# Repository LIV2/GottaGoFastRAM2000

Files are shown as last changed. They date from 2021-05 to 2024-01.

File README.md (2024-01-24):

# GottaGoFastRAM2000 8MB Autoconfig Fast RAM

This is an 8MB Autoconfig Fast RAM for the Amiga 2000 

Special thanks to [GadgetUK164](https://www.youtube.com/user/GadgetUK164) and sparxUK for their help testing this.

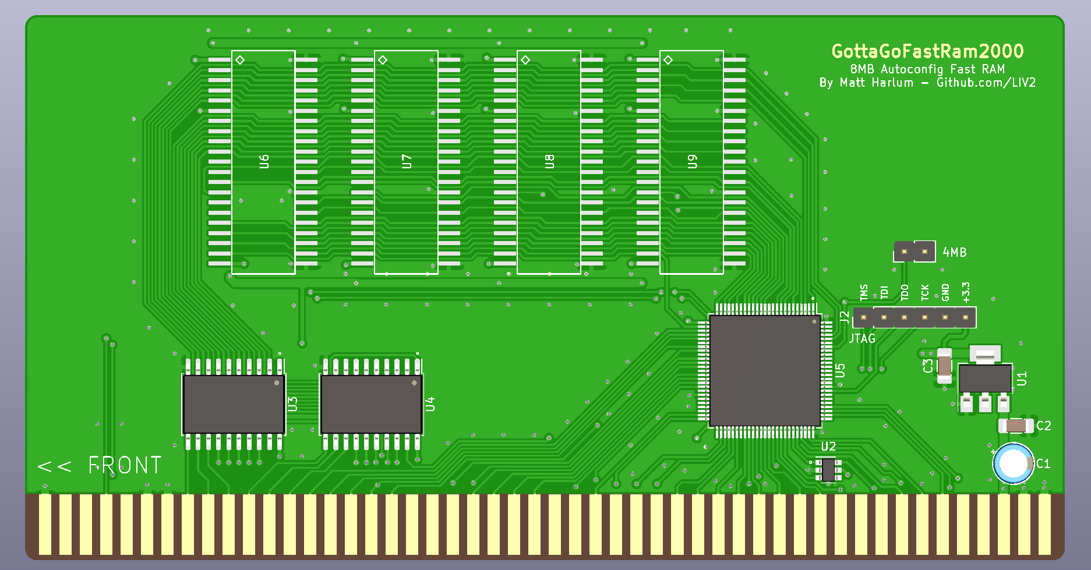
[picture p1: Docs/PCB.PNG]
PCB


## Table of contents
1. [Status](#status)
1. [Features](#features)
1. [Firmware](#firmware)
1. [PCB Ordering](#ordering-pcbs)
1. [Jumpers](#jumpers)
1. [Bill of materials](#bill-of-materials)
1. [Troubleshooting](#troubleshooting)

## Status

This is tested and working

## Features

* 8MB of Fast RAM
* Auto-sizing - The RAM board will coexist with other devices by autosizing to fit the remaining free Zorro II memory space

## Firmware

There are two different firmwares available for this card.
1. [Standard autosizing](https://github.com/LIV2/GottaGoFastRAM2000/raw/master/Binary/XC9572XL/gottagofast2000.jed) - This Firmware will autosize trying in this order: 8MB -> 4MB -> 2MB -> 1MB until it can fit in the remaining space
2. [6MB autosizing](https://github.com/LIV2/GottaGoFastRAM2000/raw/master/Binary/XC9572XL/gottagofast2000-6MB.jed) - This will try to offer 8MB then 6MB (in a block of 2MB + 4MB) to maximize space i.e when using a bridgeboard that needs 512K itself

## PCB Ordering

For best results the boards should be manufactured with the "Gold Fingers" option so that the edge connector will survive many insertion/removal cycles

## Jumpers

4MB: Forces the board to appear as a 4MB board rather than 8MB

### Bill of materials

|Component|Location|QTY|Link|Note|
|---|---|---|----|----|
|LM1117-3.3 SOT-223|U1|1|[Mouser](https://www.mouser.com/ProductDetail/926-LM1117IMP3.3NOPB)||
|XC9572XL-10TQ100C|U5|1|[Mouser](https://www.mouser.com/ProductDetail/217-C9572XL-10TQ100C)|Can be substituted with XC95144XL-10-TQ100|
|74LS245 SOIC|U3,U4|2|[Mouser](https://www.mouser.com/ProductDetail/595-SN74LS245DWR)||
|74LVC2G07|U2|1|[Mouser](https://www.mouser.com/ProductDetail/595-SN74LVC2G07DBVR)|*Optional - See below|
|5v 1MBx16 DRAM, SOJ-42  i.e  <br/>K4E151611<br/>K4F151611<br/>MT4C1M16E5<br/>GM71C18163C<br/>AS4C1M16E5 etc.|U6,U7,U8,U9|4|Aliexpress, Ebay etc||
|0.1uF Ceramic capacitor, 0805|C4-25|22|[Mouser](https://www.mouser.com/ProductDetail/581-08055C104K)||
|10uF Ceramic capacitor, 1206|C2,C3|2|[Mouser](https://www.mouser.com/ProductDetail/80-C1206C106K4R)||
|100uF Electrolytic Capacitor|C1|1|[Mouser](https://www.mouser.com/ProductDetail/667-16SEPC100M)||
|10K Resistor, 0805|R1|1|[Mouser](https://www.mouser.com/ProductDetail/754-RR1220P-103D)|

\* U2 buffers the cards generated DTACK and OVR signals - In a pinch this can be left out but you will run into problems with the A2091 and some other devices so it is best to fit this and save yourself the headache

## Troubleshooting
* **Problem**: System does not boot, the power LED does not change brightness  
  **Solution**: Possible incorrect orientation/faulty ic in U2 - check orientation and/or remove this IC and try again

* **Problem**: My bridgeboard doesn't work when this card is installed  
  **Solution**: The bridgeboard needs 512K of the 8MB expansion space for its own use, you will need to move the ram board to the leftmost slot and I recommend flashing the [6MB Firmware](https://github.com/LIV2/GottaGoFastRAM2000/raw/master/Binary/XC9572XL/gottagofast2000-6MB.jed) to maximise the amount of memory offered when used with the bridgeboard

* **Problem**: My system is unstable / graphical corruption when using this board but it passes a memory test in ATK/DiagROM etc  
  **Solution**: Check that your Amiga 2000 has the correct buffers installed in U600-605. U600,601,603,604 __must__ be 74LS245 and U602/605 should be 74ALS245 but might be 74LS245 in some A2000 revisions.  
  If you have used anything else (like 74HCT245) for these you will run into issues with this board and many others.

* **Problem**: When used with a bridgeboard/other cards I get a gray screen telling me the card has been "SHUT"  
  **Solution**: Some other board is using some of the 8MB space, so the card will be told to shutup and will reappear offering 4MB then 2, 1 etc.  
  On Kick 1.3-3.1 the system will not alert you to this happening and will continue to boot (this is used to do the autosizing) but newer versions "helpfully" tell you about this condition.  
  If using one of these newer kickstart versions with a Bridgeboard I'd recommend flashing the [6MB Firmware](https://github.com/LIV2/GottaGoFastRAM2000/raw/master/Binary/XC9572XL/gottagofast2000-6MB.jed)  
  Another option would be to write the firmware to offer multiple 2MB blocks until it is shut up which unfortunately doesn't work, because Kickstart 1.3-3.1 will throw a yellow screen if the last board in the chain was shut up, and newer versions will throw the gray screen telling us the board has been shut-up.
  
* **Problem**: With the board installed I get a red screen saying that this board is defective  
  **Solution**: This usually means that one of the RAM chips are faulty or there could be bad soldering.  
  Remove all other Zorro cards, boot up [ATK](https://github.com/keirf/amiga-stuff/releases) or Diagrom and do a manual memory test with the individual ranges listed in the memory map below.  
  Consult the memory map below to figure out which RAM chip is being reported faulty.
  If the same bits are reported as faulty across multiple of the address ranges check for bad soldering around the RAM chips and the buffers at U3&U4.  

### Memory Map
|Address range|Chip|
|---|----|
|200000-3FFFFF|U6|
|400000-5FFFFF|U7|
|600000-7FFFFF|U8|
|800000-9FFFFF|U9|

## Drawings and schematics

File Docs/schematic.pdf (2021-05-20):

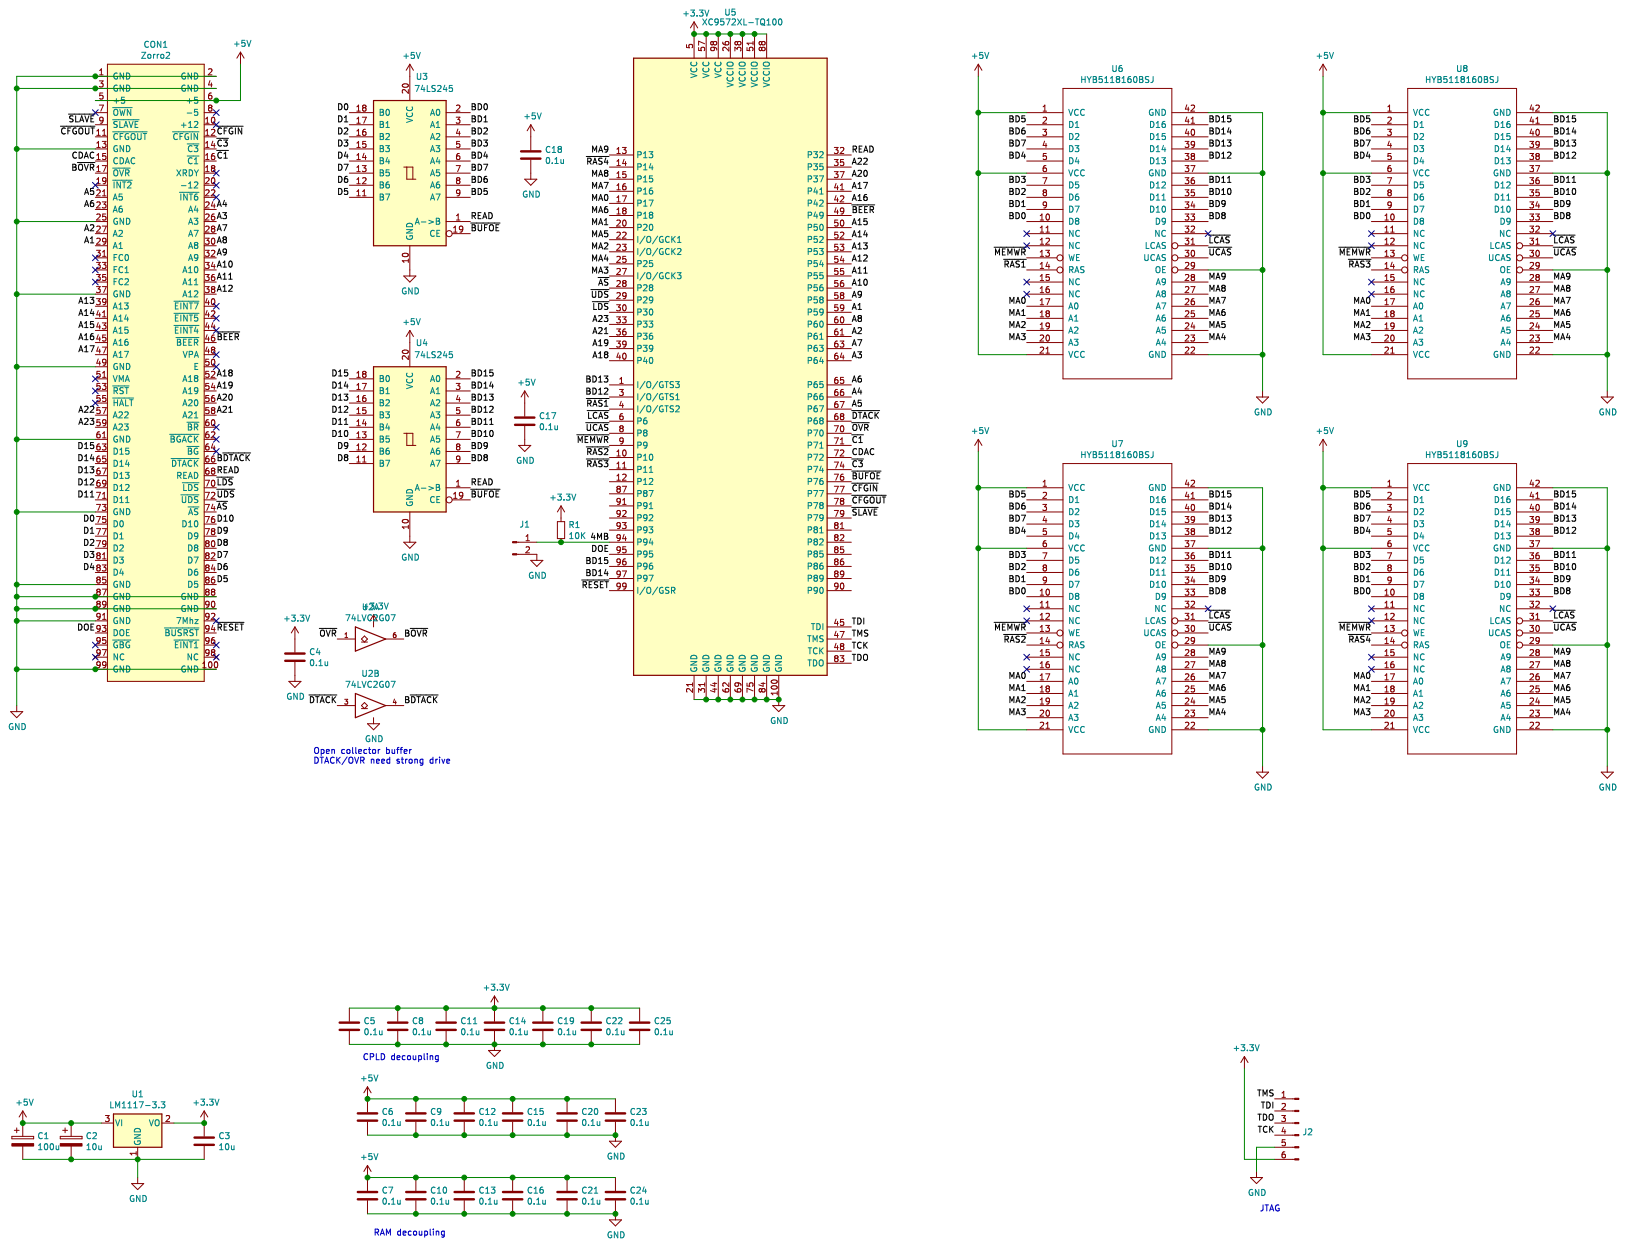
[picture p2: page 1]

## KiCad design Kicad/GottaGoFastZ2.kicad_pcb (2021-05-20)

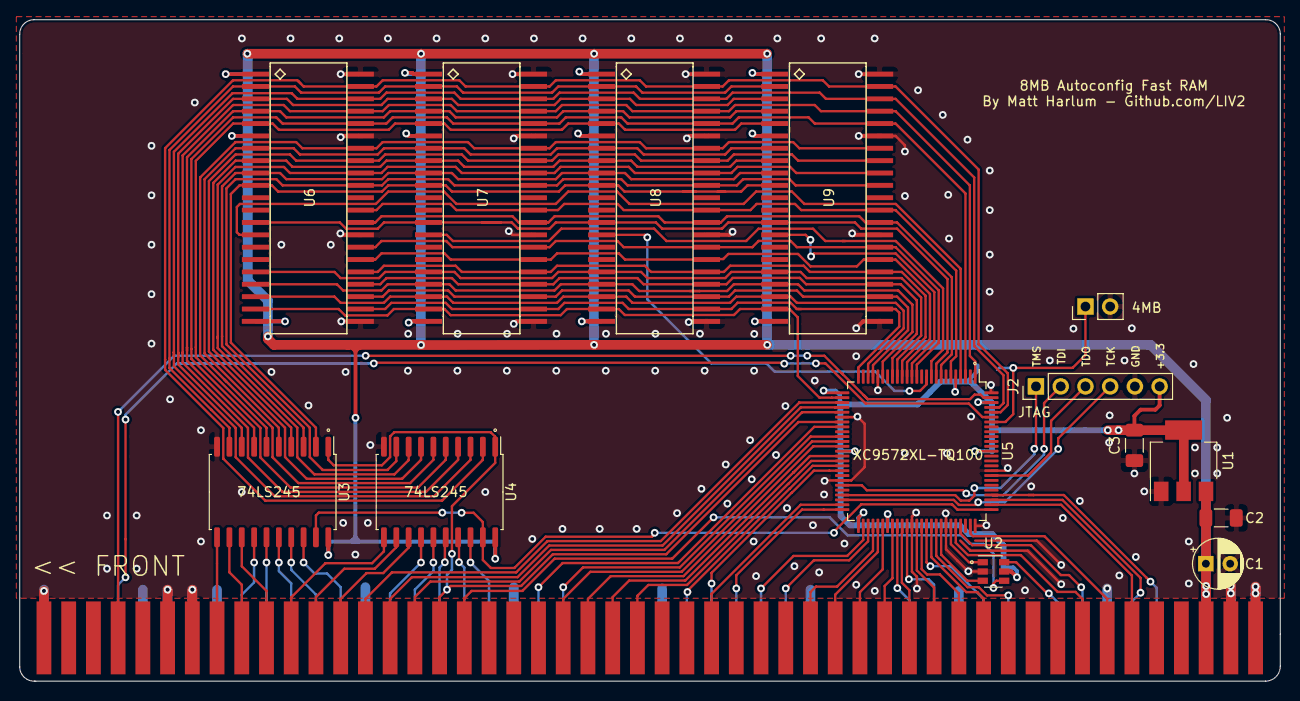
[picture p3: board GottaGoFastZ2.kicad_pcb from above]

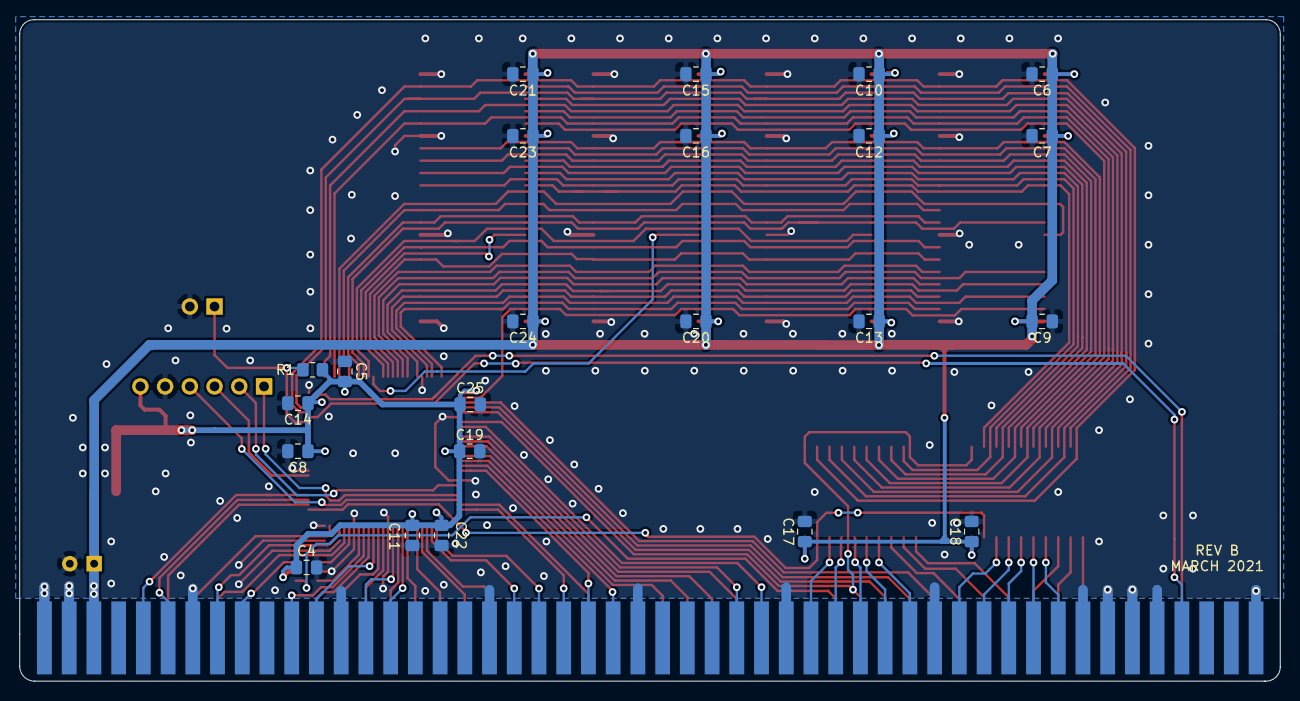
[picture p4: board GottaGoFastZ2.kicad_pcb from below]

Board: 2 copper layers, 129.5 x 67.9 mm, 38 parts (23 on the bottom side), 98 nets.

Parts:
C1: 100u; CP_Radial_D5.0mm_P2.50mm
C2, C3: 10u; C_1206_3216Metric_Pad1.33x1.80mm_HandSolder
C4, C5, C6, C7, C8, C9, C10, C11, C12, C13, C14, C15, C16, C17, C18, C19, C20, C21, C22, C23, C24, C25: 0.1u; C_0805_2012Metric_Pad1.18x1.45mm_HandSolder
CON1: Zorro2; Zorro2-CardEdge
J1: 4MB; PinHeader_1x02_P2.54mm_Vertical
J2: Conn_01x06_Male; PinHeader_1x06_P2.54mm_Vertical
R1: 10K; R_0805_2012Metric_Pad1.20x1.40mm_HandSolder
U1: LM1117-3.3; SOT-223-3_TabPin2
U2: 74LVC2G07; SOT-23-6
U3, U4: 74LS245; SOIC-20W_7.5x12.8mm_P1.27mm
U5: XC9572XL-TQ100; TQFP-100_14x14mm_P0.5mm
U6, U7, U8, U9: HYB5118160BSJ; SOJ-42-LongPads

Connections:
+3V3: C3.1, C4.1, C5.1, C8.1, C11.1, C14.1, C19.1, C22.1, C25.1, J2.6, R1.1, U1.2, U2.5, U5.5, U5.26, U5.38, U5.51, U5.57, U5.88, U5.98
+5V: C1.1, C2.1, C6.1, C7.1, C9.1, C10.1, C12.1, C13.1, C15.1, C16.1, C17.1, C18.1, C20.1, C21.1, C23.1, C24.1, CON1.5, CON1.6, U1.3, U3.20, U4.20, U6.1, U6.6, U6.21, U7.1, U7.6, U7.21, U8.1, U8.6, U8.21, U9.1, U9.6, U9.21
/4MB: J1.1, R1.2, U5.94
/A1: CON1.29, U5.59
/A2: CON1.27, U5.61
/A3: CON1.26, U5.64
/A4: CON1.24, U5.66
/A5: CON1.21, U5.67
/A6: CON1.23, U5.65
/A7: CON1.28, U5.63
/A8: CON1.30, U5.60
/A9: CON1.32, U5.58
/A10: CON1.34, U5.56
/A11: CON1.36, U5.55
/A12: CON1.38, U5.54
/A13: CON1.39, U5.53
/A14: CON1.41, U5.52
/A15: CON1.43, U5.50
/A16: CON1.45, U5.42
/A17: CON1.47, U5.41
/A18: CON1.52, U5.40
/A19: CON1.54, U5.39
/A20: CON1.56, U5.37
/A21: CON1.58, U5.36
/A22: CON1.57, U5.35
/A23: CON1.59, U5.33
/BD0: U3.2, U6.10, U7.10, U8.10, U9.10
/BD1: U3.3, U6.9, U7.9, U8.9, U9.9
/BD2: U3.4, U6.8, U7.8, U8.8, U9.8
/BD3: U3.5, U6.7, U7.7, U8.7, U9.7
/BD4: U3.6, U6.5, U7.5, U8.5, U9.5
/BD5: U3.9, U6.2, U7.2, U8.2, U9.2
/BD6: U3.8, U6.3, U7.3, U8.3, U9.3
/BD7: U3.7, U6.4, U7.4, U8.4, U9.4
/BD8: U4.9, U6.33, U7.33, U8.33, U9.33
/BD9: U4.8, U6.34, U7.34, U8.34, U9.34
/BD10: U4.7, U6.35, U7.35, U8.35, U9.35
/BD11: U4.6, U6.36, U7.36, U8.36, U9.36
/BD12: U4.5, U5.3, U6.38, U7.38, U8.38, U9.38
/BD13: U4.4, U5.1, U6.39, U7.39, U8.39, U9.39
/BD14: U4.3, U5.97, U6.40, U7.40, U8.40, U9.40
/BD15: U4.2, U5.96, U6.41, U7.41, U8.41, U9.41
/B~DTACK: CON1.66, U2.4
/B~OVR: CON1.17, U2.6
/CDAC: CON1.15, U5.72
/D0: CON1.75, U3.18
/D1: CON1.77, U3.17
/D2: CON1.79, U3.16
/D3: CON1.81, U3.15
/D4: CON1.83, U3.14
/D5: CON1.86, U3.11
/D6: CON1.84, U3.12
/D7: CON1.82, U3.13
/D8: CON1.80, U4.11
/D9: CON1.78, U4.12
/D10: CON1.76, U4.13
/D11: CON1.71, U4.14
/D12: CON1.69, U4.15
/D13: CON1.67, U4.16
/D14: CON1.65, U4.17
/D15: CON1.63, U4.18
/DOE: CON1.93, U5.95
/MA0: U5.17, U6.17, U7.17, U8.17, U9.17
/MA1: U5.20, U6.18, U7.18, U8.18, U9.18
/MA2: U5.23, U6.19, U7.19, U8.19, U9.19
/MA3: U5.27, U6.20, U7.20, U8.20, U9.20
/MA4: U5.25, U6.23, U7.23, U8.23, U9.23
/MA5: U5.22, U6.24, U7.24, U8.24, U9.24
/MA6: U5.18, U6.25, U7.25, U8.25, U9.25
/MA7: U5.16, U6.26, U7.26, U8.26, U9.26
/MA8: U5.15, U6.27, U7.27, U8.27, U9.27
/MA9: U5.13, U6.28, U7.28, U8.28, U9.28
/READ: CON1.68, U3.1, U4.1, U5.32
/TCK: J2.4, U5.48
/TDI: J2.2, U5.45
/TDO: J2.3, U5.83
/TMS: J2.1, U5.47
/~AS: CON1.74, U5.28
/~BEER: CON1.46, U5.49
/~BUFOE: U3.19, U4.19, U5.76
/~C1: CON1.16, U5.71
/~C3: CON1.14, U5.74
/~CFGIN: CON1.12, U5.77
/~CFGOUT: CON1.11, U5.78
/~DTACK: U2.3, U5.68
/~LCAS: U5.6, U6.31, U7.31, U8.31, U9.31
/~LDS: CON1.70, U5.30
/~MEMWR: U5.9, U6.13, U7.13, U8.13, U9.13
/~OVR: U2.1, U5.70
/~RAS1: U5.4, U6.14
/~RAS2: U5.10, U7.14
/~RAS3: U5.11, U8.14
/~RAS4: U5.14, U9.14
/~RESET: CON1.94, U5.99
/~SLAVE: CON1.9, U5.79
/~UCAS: U5.8, U6.30, U7.30, U8.30, U9.30
/~UDS: CON1.72, U5.29
GND: C1.2, C2.2, C3.2, C4.2, C5.2, C6.2, C7.2, C8.2, C9.2, C10.2, C11.2, C12.2, C13.2, C14.2, C15.2, C16.2, C17.2, C18.2, C19.2, C20.2, C21.2, C22.2, C23.2, C24.2, C25.2, CON1.1, CON1.2, CON1.3, CON1.4, CON1.13, CON1.25, CON1.37, CON1.49, CON1.61, CON1.73, CON1.85, CON1.87, CON1.88, CON1.89, CON1.90, CON1.91, CON1.99, CON1.100, J1.2, J2.5, U1.1, U2.2, U3.10, U4.10, U5.21, U5.31, U5.44, U5.62, U5.69, U5.75, U5.84, U5.100, U6.22, U6.29, U6.37, U6.42, U7.22, U7.29, U7.37, U7.42, U8.22, U8.29, U8.37, U8.42, U9.22, U9.29, U9.37, U9.42

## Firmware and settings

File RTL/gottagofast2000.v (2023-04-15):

/*
GottaGoFastRAMZ2 - Zorro 2 8MB Autoconfig FastRAM for Amiga 2000
Copyright 2021 Matthew Harlum

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
*/

// Config defines
`ifndef makefile_defines
`define SERIAL 32'd421
`define autoconfig  // If disabled RAM is always mapped to $200000-9FFFFF
//`define Offer_6M  // If told to shutup when offering 8MB, offer up a 2MB and also 4MB block next (useful with an A590/2091)
`endif

module gottagofast2000(
    input C1n,
    input C3n,
    input CDAC,
    input DOE,
    input RESETn,
    input CFGINn,
    input UDSn,
    input LDSn,
    input ASn,
    input RWn,
    input J4MB,
    input BERRn,
    input [23:1] ADDR,
    inout [15:12] DBUS,
    output reg [9:0] MADDR,
    output reg CFGOUTn,
    output RAS1n,
    output RAS2n,
    output RAS3n,
    output RAS4n,
    output UCASn,
    output LCASn,
    output OEn,
    output SLAVEn,
    output MEMWn,
    output reg DTACKn,
    output OVRn
    );


wire CLK;
assign CLK = !(C1n ^ C3n); // Generate 7MHz clock from C1n XOR C3n

wire autoconfig_cycle;
`ifndef autoconfig
assign autoconfig_cycle = 0;
`else
// Autoconfig
localparam [15:0] mfg_id  = 16'd5194;
localparam [7:0]  prod_id = 8'd2;
localparam [31:0] serial = `SERIAL;

reg [7:0] addr_match;
reg CFGINnr;
reg shutup;
reg configured;
reg [2:0] autoconfig_state;
reg [3:0] data_out;

localparam   Offer_8M = 3'b000,
// If offering 2MB + 4MB blocks you need to offer the 2MB block first
// This is because of a kickstart bug where the memory config overflows if there is already 2MB configured before another 4MB then 2MB is configured...
`ifdef Offer_6M
        Offer_2M = 3'b001,
        Offer_4M = 3'b010,
`else
        Offer_4M = 3'b001,
        Offer_2M = 3'b010,
`endif
        Offer_1M = 3'b011,
        SHUTUP   = 3'b100;

assign DBUS[15:12] = (autoconfig_cycle & RWn & !ASn & !UDSn) ? data_out[3:0] : 4'bZ;

assign autoconfig_cycle = (ADDR[23:16] == 8'hE8) & !CFGINnr & CFGOUTn;

// Register Config in/out at end of bus cycle
always @(posedge ASn or negedge RESETn)
begin
  if (!RESETn) begin
    CFGOUTn <= 1'b1;
    CFGINnr <= 1'b1;
  end else begin
    CFGOUTn <= !shutup;
    CFGINnr <= CFGINn;
  end
end

// Offers an 8MB block first, if there's no space offer 4MB, 2MB then 1MB before giving up
always @(negedge UDSn or negedge RESETn)
begin
  if (!RESETn) begin
    data_out <= 'bZ;
    configured <= 1'b0;
    shutup <= 1'b0;
    addr_match <= 8'b00000000;

`ifdef Offer_6M
  autoconfig_state <= Offer_2M; // Offer 6MB Only (2+4)
`else
    if (!J4MB) begin
      autoconfig_state <= Offer_4M;
    end else begin
      autoconfig_state <= Offer_8M;
    end
`endif
  end else if (autoconfig_cycle & RWn) begin
    case (ADDR[8:1])
      8'h00:   data_out <= 4'b1110;        // Type: Zorro II, link to free pool
      8'h01:
        case (autoconfig_state)
          Offer_8M: data_out <= 4'b0000;
          Offer_4M: data_out <= 4'b0111;
          Offer_2M: data_out <= 4'b0110;
          Offer_1M: data_out <= 4'b0101;
          default:  data_out <= 4'b0000;
        endcase
      8'h02:   data_out <= ~prod_id[7:4];  // Product number
      8'h03:   data_out <= ~prod_id[3:0];  // Product number
      8'h04:   data_out <= ~4'b1000;       // Place in 8M Space
      8'h05:   data_out <= ~4'b0000;       // Logical size matches physical size
      8'h08:   data_out <= ~mfg_id[15:12]; // Manufacturer ID
      8'h09:   data_out <= ~mfg_id[11:8];  // Manufacturer ID
      8'h0A:   data_out <= ~mfg_id[7:4];   // Manufacturer ID
      8'h0B:   data_out <= ~mfg_id[3:0];   // Manufacturer ID
      8'h0C:   data_out <= ~serial[31:28]; // Serial number
      8'h0D:   data_out <= ~serial[27:24]; // Serial number
      8'h0E:   data_out <= ~serial[23:20]; // Serial number
      8'h0F:   data_out <= ~serial[19:16]; // Serial number
      8'h10:   data_out <= ~serial[15:12]; // Serial number
      8'h11:   data_out <= ~serial[11:8];  // Serial number
      8'h12:   data_out <= ~serial[7:4];   // Serial number
      8'h13:   data_out <= ~serial[3:0];   // Serial number
      default: data_out <= 4'hF;
    endcase
  end else if (autoconfig_cycle & !ASn & !RWn) begin
    if (ADDR[8:1] == 8'h26) begin
      // We've been told to shut up (not enough memory space)
      // Try offering a smaller block
      if (autoconfig_state >= SHUTUP-1) begin
        // All options exhausted - time to shut up!
        shutup <= 1;
        autoconfig_state <= SHUTUP;
      end else begin
        // Offer the next smallest block
        autoconfig_state <= autoconfig_state + 1;
      end
    end
    else if (ADDR[8:1] == 8'h24) begin
      // Configure the memory block assigned to us by the Amiga
      //
      // addr_match is an array of 1MB blocks.
      // This is so the card can make multiple offers to Autoconfig & accept multiple address allocations at the same time
      // i.e to facilitate a 6MB config by appearing as a 2MB card and a 4MB card.
      case (autoconfig_state)
        Offer_8M:
          begin
            addr_match <= 8'hFF;
            shutup     <= 1'b1;
          end
        Offer_4M:
          begin
            case(DBUS)
              4'h2:    addr_match <= (addr_match|8'b00001111);
              4'h4:    addr_match <= (addr_match|8'b00111100);
              4'h6:    addr_match <= (addr_match|8'b11110000);
            endcase
            shutup     <= 1'b1;
          end
        Offer_2M:
          begin
            case(DBUS)
              4'h2:    addr_match <= (addr_match|8'b00000011);
              4'h4:    addr_match <= (addr_match|8'b00001100);
              4'h6:    addr_match <= (addr_match|8'b00110000);
              4'h8:    addr_match <= (addr_match|8'b11000000);
            endcase
            `ifdef Offer_6M
            autoconfig_state <= Offer_4M;
            `else
            shutup     <= 1'b1;
            `endif
          end
        Offer_1M:
          begin
            case(DBUS)
              4'h2:    addr_match <= (addr_match|8'b00000001);
              4'h3:    addr_match <= (addr_match|8'b00000010);
              4'h4:    addr_match <= (addr_match|8'b00000100);
              4'h5:    addr_match <= (addr_match|8'b00001000);
              4'h6:    addr_match <= (addr_match|8'b00010000);
              4'h7:    addr_match <= (addr_match|8'b00100000);
              4'h8:    addr_match <= (addr_match|8'b01000000);
              4'h9:    addr_match <= (addr_match|8'b10000000);
            endcase
            shutup     <= 1'b1;
          end
        default:  addr_match <= 8'b0;
      endcase
      configured <= 1'b1;
    end
  end
end

`endif

// Memory controller

reg ram_cycle;
reg access_ras;
reg access_ucas;
reg access_lcas;
reg refresh_ras;
reg refresh_cas;
wire ram_addrmatched;
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

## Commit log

2021-05-20 Initial Public release
    [GottaGoFastZ2-B_Cu.gbr, GottaGoFastZ2-B_Mask.gbr, GottaGoFastZ2-B_SilkS.gbr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]
2021-06-15 Fixup BOM
    Add R1
    Correct P/N for LS245's
2021-07-25 Fixup 6MB option, fix Makefile line endings
    [gottagofast2000.v]
2022-01-07 Bugfixes * Change slew to slow * Make sure autoconfig_cycle is held through the whole cycle instead of releasing immediately
    [gottagofast2000.v]
2023-04-15 Switch to OHR assigned autoconfig id
2026-03-15 Add note to BOM for DRAM to assist in selecting substitutes

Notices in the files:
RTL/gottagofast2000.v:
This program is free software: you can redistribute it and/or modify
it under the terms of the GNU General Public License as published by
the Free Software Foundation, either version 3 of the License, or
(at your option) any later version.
